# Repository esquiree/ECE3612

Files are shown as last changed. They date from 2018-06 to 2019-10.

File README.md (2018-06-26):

# ECE3612
## `Dr. Helferty's` break out board for the ATmega 324PB
_Designed by Reed Esquirell_
---

---
This PCB is designed around the ATMEL ATmega324PB XPLAINED PRO kit.  It organizes ports A-E while providing features to the programmer.  Including:
* Potentiometer for ADC
* 8 LEDs for outputs
* 8 DIP switches for input
* Seven Segment Display (SSD)
* Stepper motor circuit
* DC motor circuit
* PMOD, I2C, UART, SERVO and PING headers

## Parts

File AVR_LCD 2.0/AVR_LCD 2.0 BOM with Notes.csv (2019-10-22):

Component | Description | Part | Designer Desciption | Example Item | References | Value | Footprint | Quantity Per PCB | Datasheet
1 | Generic connector, double row, 02x10, odd/even pin numbering scheme (row 1 odd numbers, row 2 even numbers), script generated (kicad-library-utils/schlib/autogen/connector/) | Conn_02x10_Odd_Even | 2 by 10 0.1 Inch Right angle female pin header | https://www.ebay.com/itm/5PCS-2x10Pin-2-54mm-Pitch-Header-Right-Angle-Female-Double-Row-Socket-Connector/132474485107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 | BreakOut_EXT1 X-Plained_EXT1 | Conn_02x10_Odd_Even | Pin_Header_Straight_2x10_Pitch2.54mm | 2 | ~
2 | Unpolarized capacitor | C | 1uF 0805 Cap |  | C1 C2 C3 | 1uF | C_0805 | 3 | ~
3 | LED generic | LED | Green 0805 LED |  | D1 | LED | LED_0805 | 1 | ~
4 | Generic connector, single row, 01x02, script generated (kicad-library-utils/schlib/autogen/connector/) | Conn_01x02 | Battery Connector | https://www.digikey.com/product-detail/en/B2B-PH-K-S(LF)(SN)/455-1704-ND/926611/?itemSeq=284861168 | J5 | Conn_01x02 | JST_XH_B02B-XH-A_02x2.50mm_Straight | 1 | ~
5 | Generic connector, single row, 01x04, script generated (kicad-library-utils/schlib/autogen/connector/) | Conn_01x04 | 4 pos 0.1 Inch FEMALE pin header |  | J1 J2 J4 | Conn_01x04 | Pin_Header_Straight_1x04_Pitch2.54mm | 3 | ~
6 | Generic connector, double row, 02x02, odd/even pin numbering scheme (row 1 odd numbers, row 2 even numbers), script generated (kicad-library-utils/schlib/autogen/connector/) | Conn_02x02_Odd_Even | 4 pos 0.1 Inch FEMALE pin header |  | J3 | Conn_02x02_Odd_Even | Pin_Header_Straight_2x02_Pitch2.54mm | 1 | ~
7 | Resistor | R | 10k 1% |  | R2 R3 | 10K | R_0805 | 2 | ~
8 | Resistor | R | 10k 1% |  | R1 R4 | 1K | R_0805 | 2 | ~
9 | ALS31313KLEATR-1000 | ALS31313 | IC | https://www.digikey.com/product-detail/en/allegro-microsystems-llc/ALS31313KLEATR-1000/620-2007-1-ND/9805849 | U4 | ALS31313 | TSSOP-8_4.4x3mm_Pitch0.65mm | 1
10 | 0.96" I2C IIC SPI Serial 128X64 White OLED LCD LED Display Module XS | I2C_LCD | WHITE I2C LCD | https://www.ebay.com/itm/0-96-I2C-IIC-SPI-Serial-128X64-White-OLED-LCD-LED-Display-Module-XS/332947056186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 | U2 | I2C_LCD | SSD1306 | 1
11 | Generic connector, single row, 01x04, script generated (kicad-library-utils/schlib/autogen/connector/) | Conn_01x04 | 4 pos 0.1 Inch MALE pin header |  | NONE | VIEW PICTURES TO RIGHT |  | 1
12 |  | Conn_01x01 | 1 pos 0.1 Inch MALE pin header |  | NONE | VIEW PICTURES TO RIGHT |  | 4
13 | LSM6DS3TR | JOYSTICK_JS5208 | Joystick | https://www.digikey.com/products/en?keywords=eg4561-nd | U5 | JOYSTICK_JS5208 | JS5208 | 1
14 | I2C/SPI, iNEMO inertial module: always-on 3D accelerometer and 3D gyroscope | LSM6DS3 | IMU | https://www.digikey.com/product-detail/en/LSM6DS3TR/497-15383-1-ND/5180534/?itemSeq=284858849 | U1 | LSM6DS3 | Bosch_LGA-14_3x2.5mm_Pitch0.5mm | 1 | www.st.com/resource/en/datasheet/lsm6ds3.pdf
15 | TMP75AIDGKR | TMP75 | Temp Sensor | https://www.digikey.com/product-detail/en/texas-instruments/TMP75AIDGKR/296-26837-1-ND/2255196 | U3 | TMP75 | 8-TSSOP (1.27mm PITCH, 5.4mm WIDTH) | 1
 |  |  |  |  |  |  |  |  |  | *** TRIM EXCESS HEIGHT FROM HEADERS
Component Groups: | 15
Component Count: | 25
Fitted Components: | 25
Number of PCBs: | 1
Total components: | 25
Schematic Version:
Schematic Date:
BoM Date: | 2/20/2019 17:40
Schematic Source: | C:\Users\Reed\Documents\Doc H LCD\AVR_LCD 2.0\AVR_LCD 2.0.sch
KiCad Version: | Eeschema (5.0.0)

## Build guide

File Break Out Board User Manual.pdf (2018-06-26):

# Break Out Board User Manual

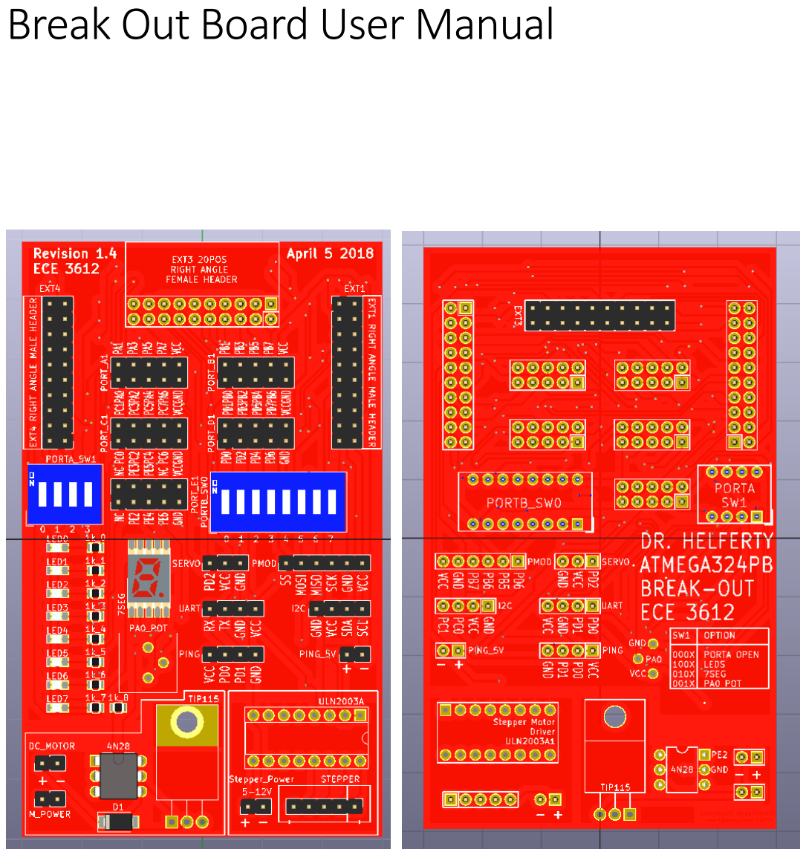
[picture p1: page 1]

## Contents

PORT A | 3
1. Analog Input (ADC0-7) | 3
2. LED Output | 3
3. Seven Segment Display | 4
PORT B | 4
1. DIP Switch | 4
2. PMOD | 4
PORT C | 5
1. I2C Interface | 5
PORT D | 5
1. UART Interface | 5
2. Servo Motor | 5
3. PMOD | 5
4. PING Sensor | 6
PORT E | 6
1. DC Motor | 6
2. Stepper Motor | 6
PCB Layers | 7

## PORT A

PORT A has three purposes:

1. Analog Input (ADC0-7). PA0(ADC0) is connected to the potentiometer through PORTA_SW1. To enable the potentiometer, PORTA_SW1 needs to be set properly. The first two switches need to be turned ON (labeled 0&1 on the silkscreen), this leaves PORTA floating. If these are enabled, the analog input will be pulled to ground. Next to use the potentiometer, enable switch 2.

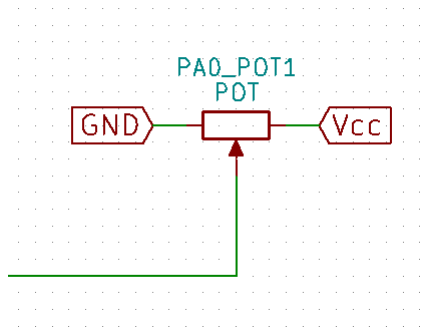
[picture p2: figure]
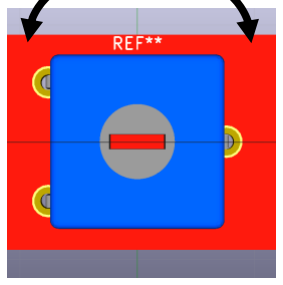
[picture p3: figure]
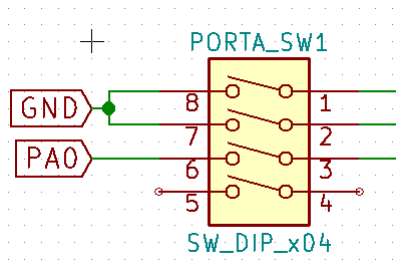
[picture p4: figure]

2. LED Output. LED0-LED7 are connected to PA0-PA7 through 1k Ohm resistors. To complete the circuit, giving the LEDs a path to ground, PORTA_SW1 0 must be enabled. If LED0 does not turn ON/OFF properly, turn off PORTA_SW1 2.
GND | VCC

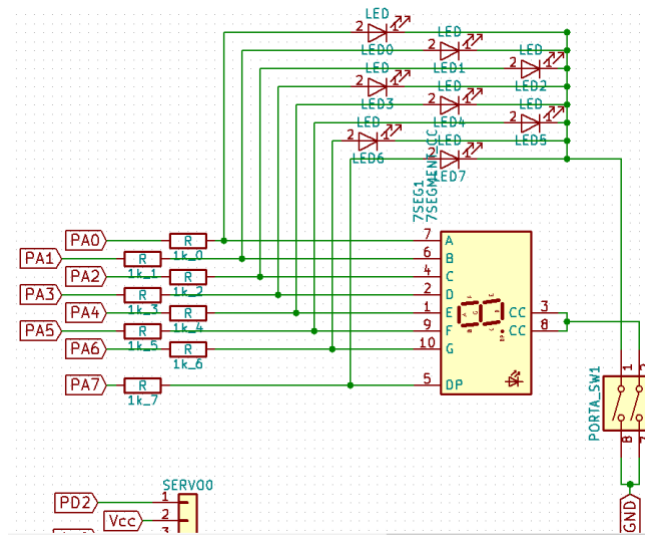
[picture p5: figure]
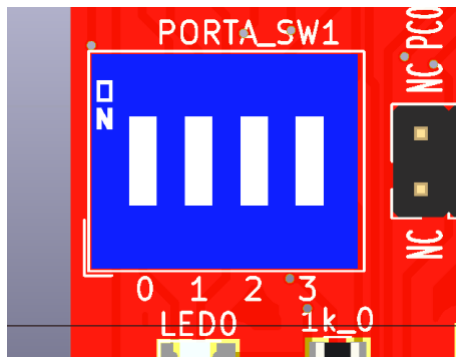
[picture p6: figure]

3. Seven Segment Display. The LEDs inside this KCS02 package use the same current limiting 1k Ohm resistors as the 8 individual LEDs. This is a common cathode (CC) device. To enable the SSD, set PORTA_SW1 1 to ON. Disable PORTA_SW1 2 if segment A is not working properly.

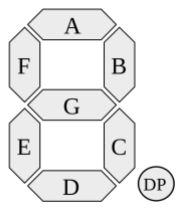
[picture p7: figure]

## PORT B

PORT B has two purposes:

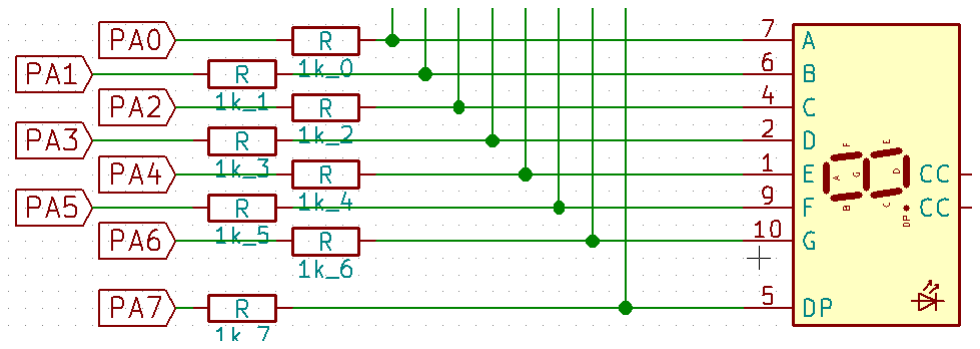
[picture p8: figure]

1. DIP Switch. This switch connects PB0-PB7 to ground when enabled. Remember to use the internal pull up resistors when using this input.

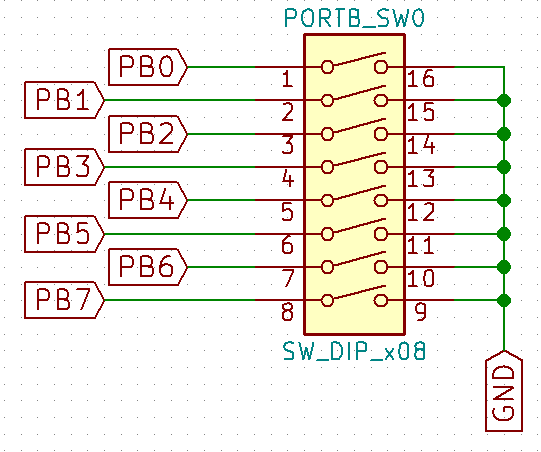
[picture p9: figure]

2. PMOD. The ATmega324PB uses PB5-PB7 for the SPI communications. When using this header, disable the corresponding switches on PORT B to leave them floating.

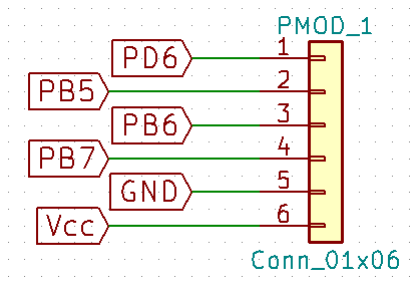
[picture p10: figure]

## PORT C

1. I2C Interface. PC0 and PC1 are used for hardware I2C communications in the ATmega 324PB. VCC is 3.3V.

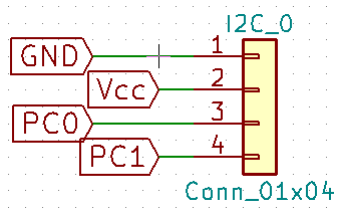
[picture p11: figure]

2. PC2-5 are used for JTAG communications and can not be accessed by default.

## PORT D

Port D has four purposes:

1. UART Interface. PD0 and PD1 are used for hardware UART communications in the ATmega 324PB. VCC is 3.3V.

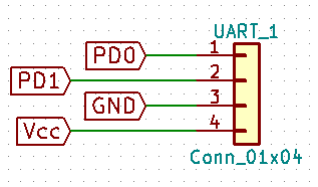
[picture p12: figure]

2. Servo Motor. PD2 is used to control the servo through PWM. VCC is 3.3V.

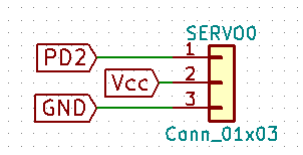
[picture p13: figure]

3. PMOD. PD6 is used as the slave select line for the hardware PMOD communications in the ATmega 324PB.

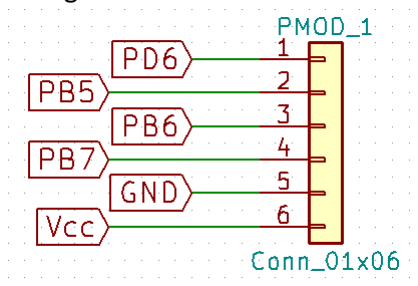
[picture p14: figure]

4. PING Sensor. The ping sensor requires 5V power. A female to female jumper wire can be used to get 5V from the USB input to the XPLAINED board.

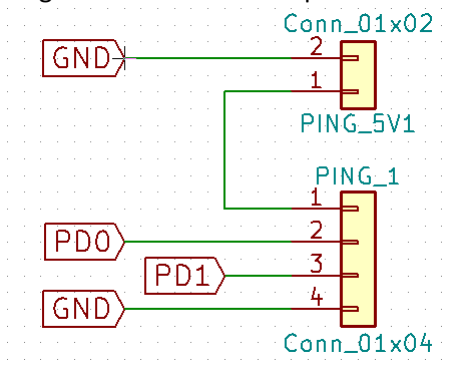
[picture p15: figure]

## PORT E

Port E has two purposes:

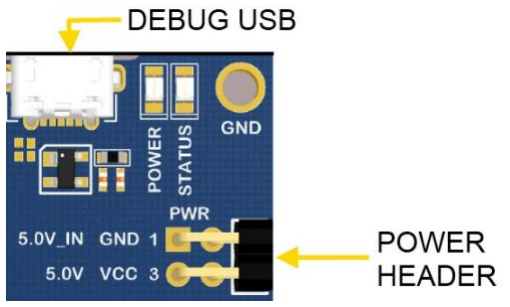
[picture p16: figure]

1. DC Motor. PE2 is connected to a 4N28 opto-isolator. This IC prevents noise and feedback from being introduced. A PNP Darlington transistor is used to amplify the signal. An external power source is needed.

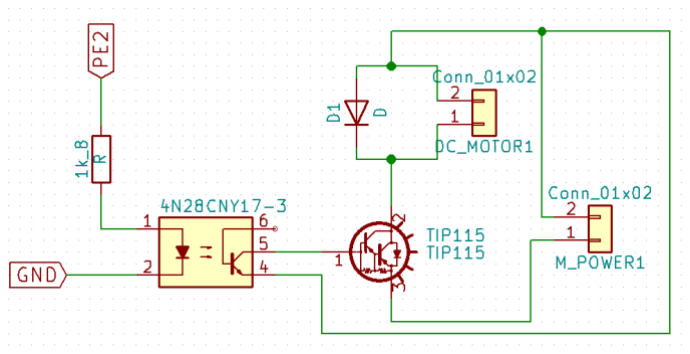
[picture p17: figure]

2. Stepper Motor. PE3-6 are connected to the ULN2003A IC. This IC amplifies the signals. An External power source is needed. 5V is the minimum and 12V is the maximum.

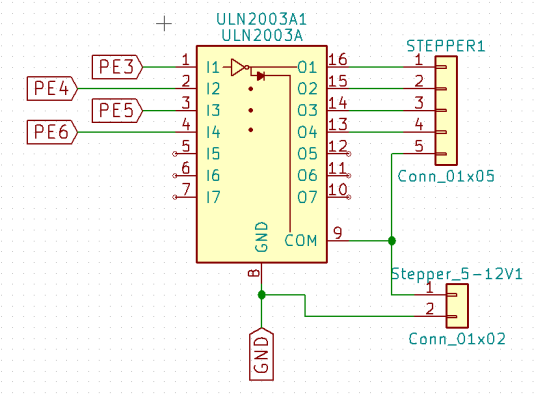
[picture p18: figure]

## PCB Layers

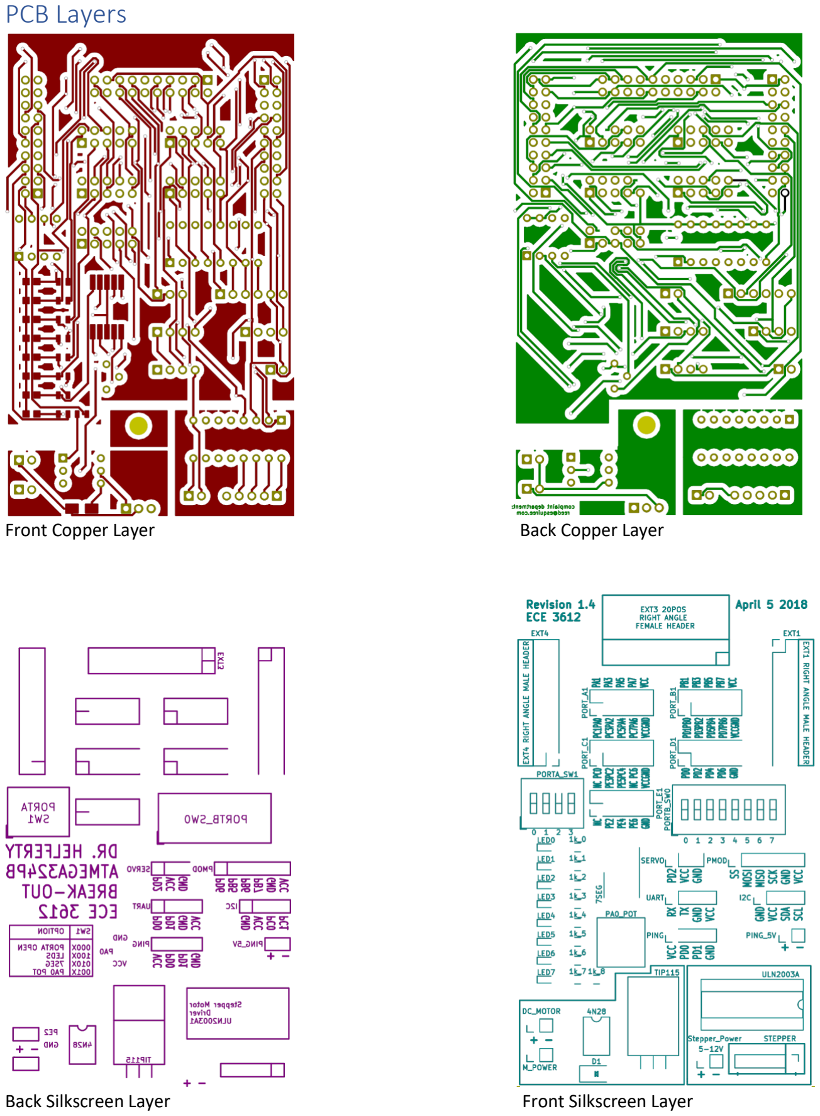
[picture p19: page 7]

Front Copper Layer | Back Copper Layer
Back Silkscreen Layer | Front Silkscreen Layer

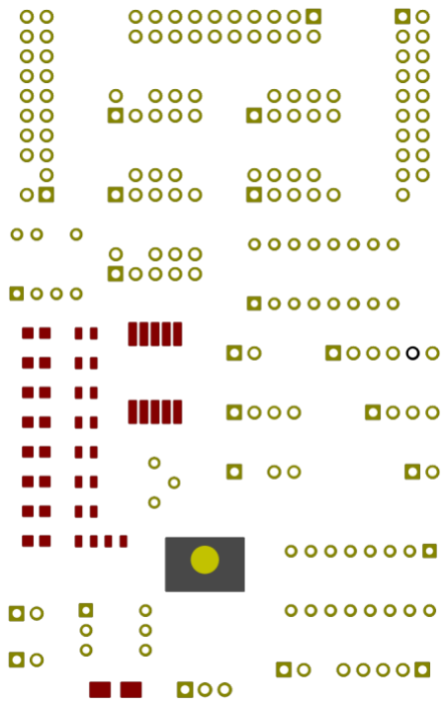
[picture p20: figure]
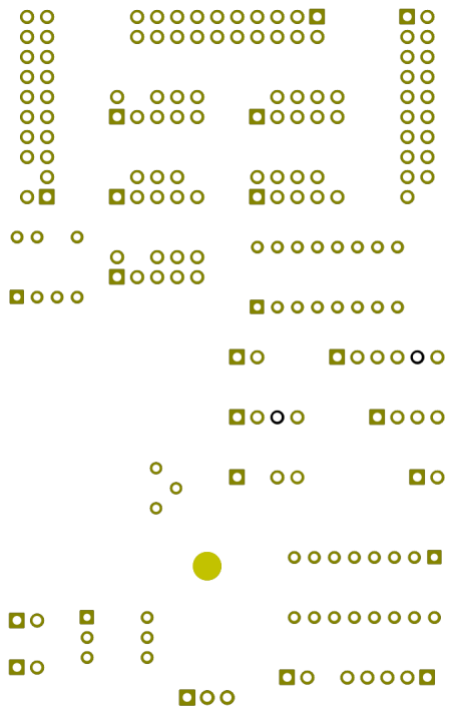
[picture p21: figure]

Front Solder Mask Layer | Bottom Solder Mask Layer

Designed using KiCad, a free and open source EDA.

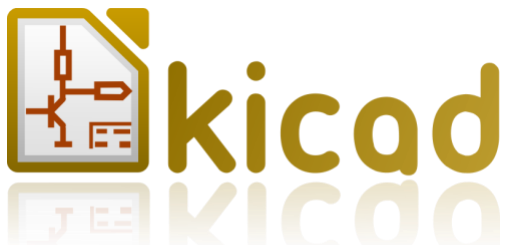
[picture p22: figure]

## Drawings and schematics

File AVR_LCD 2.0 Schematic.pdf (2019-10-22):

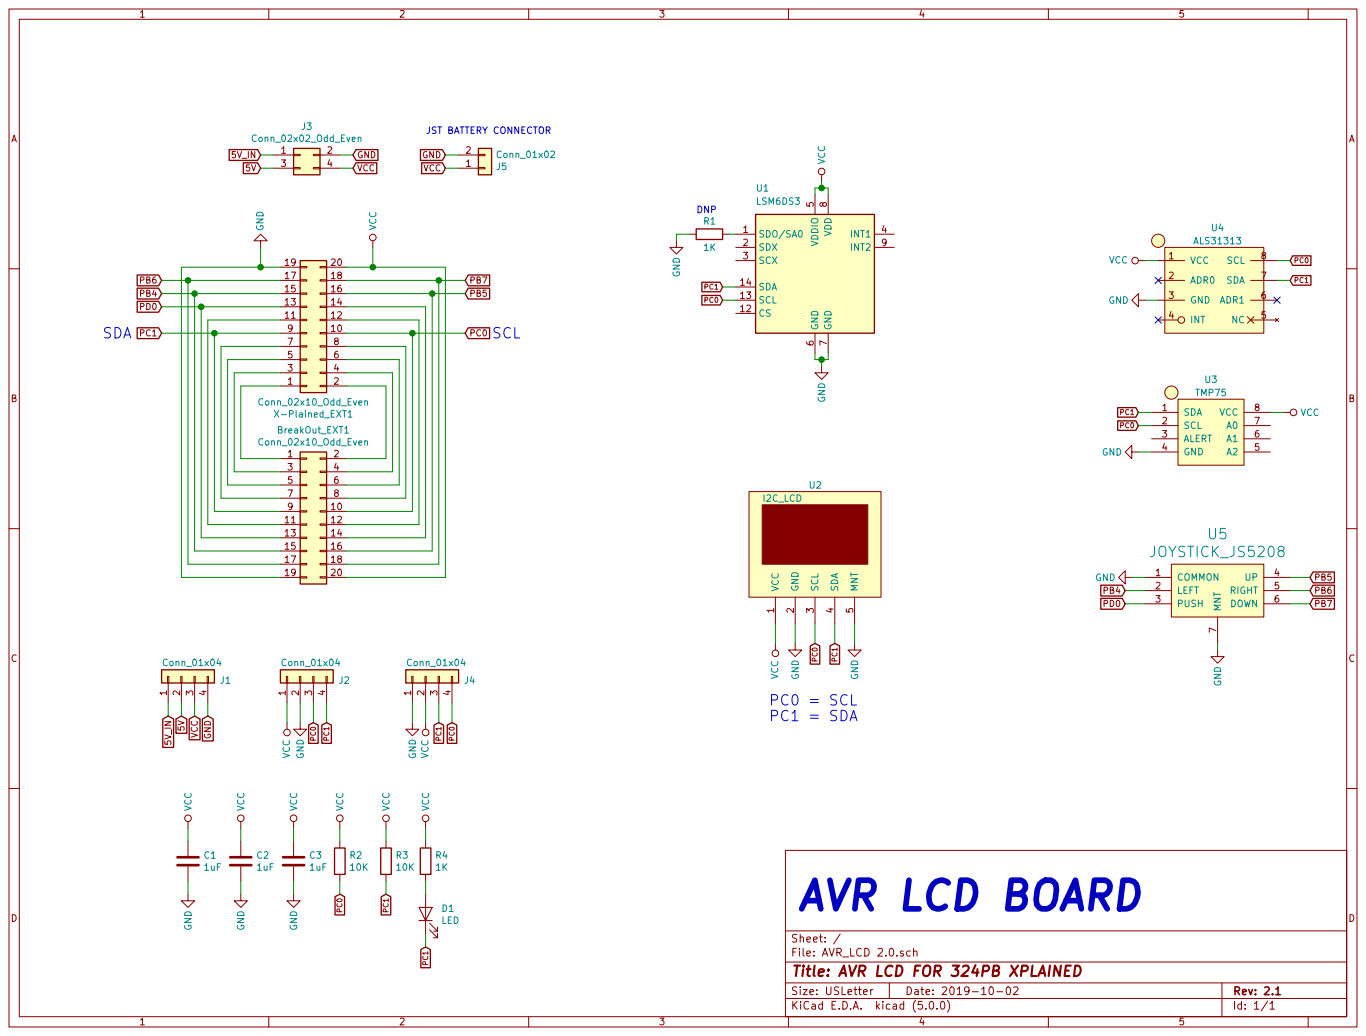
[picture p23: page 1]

Id: 1/1 Title: AVR LCD FOR 324PB XPLAINED

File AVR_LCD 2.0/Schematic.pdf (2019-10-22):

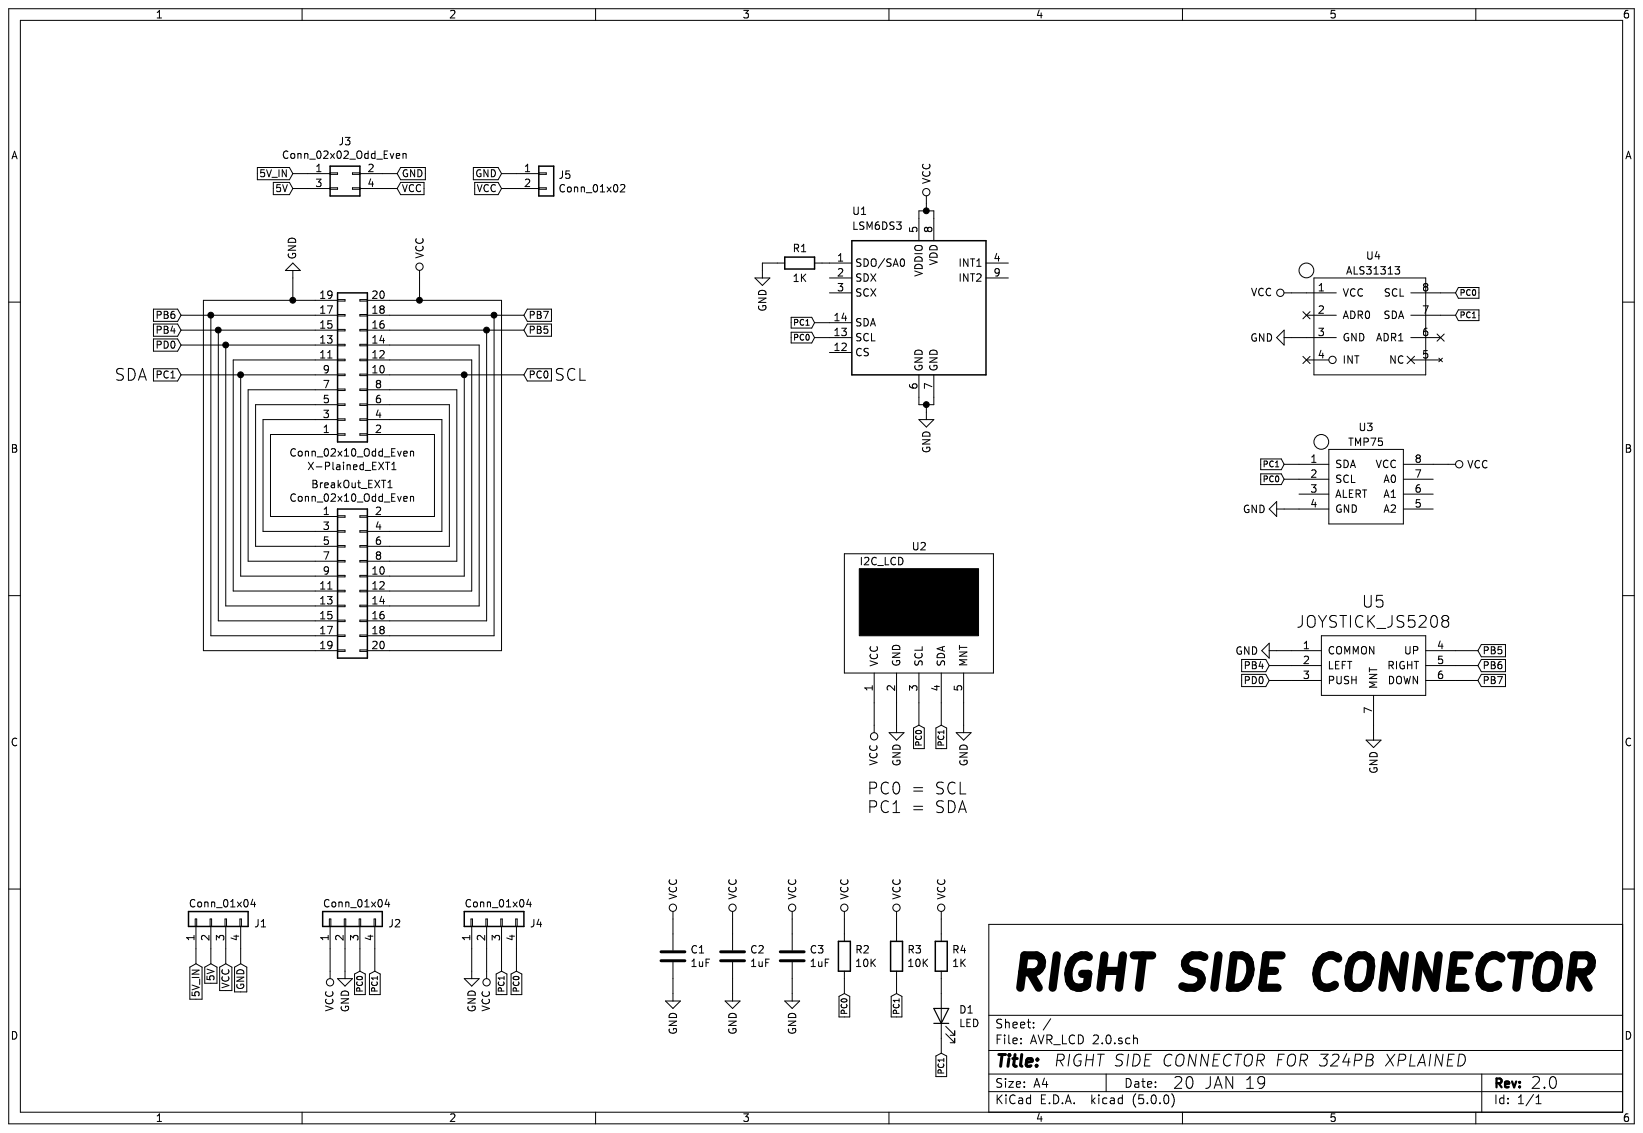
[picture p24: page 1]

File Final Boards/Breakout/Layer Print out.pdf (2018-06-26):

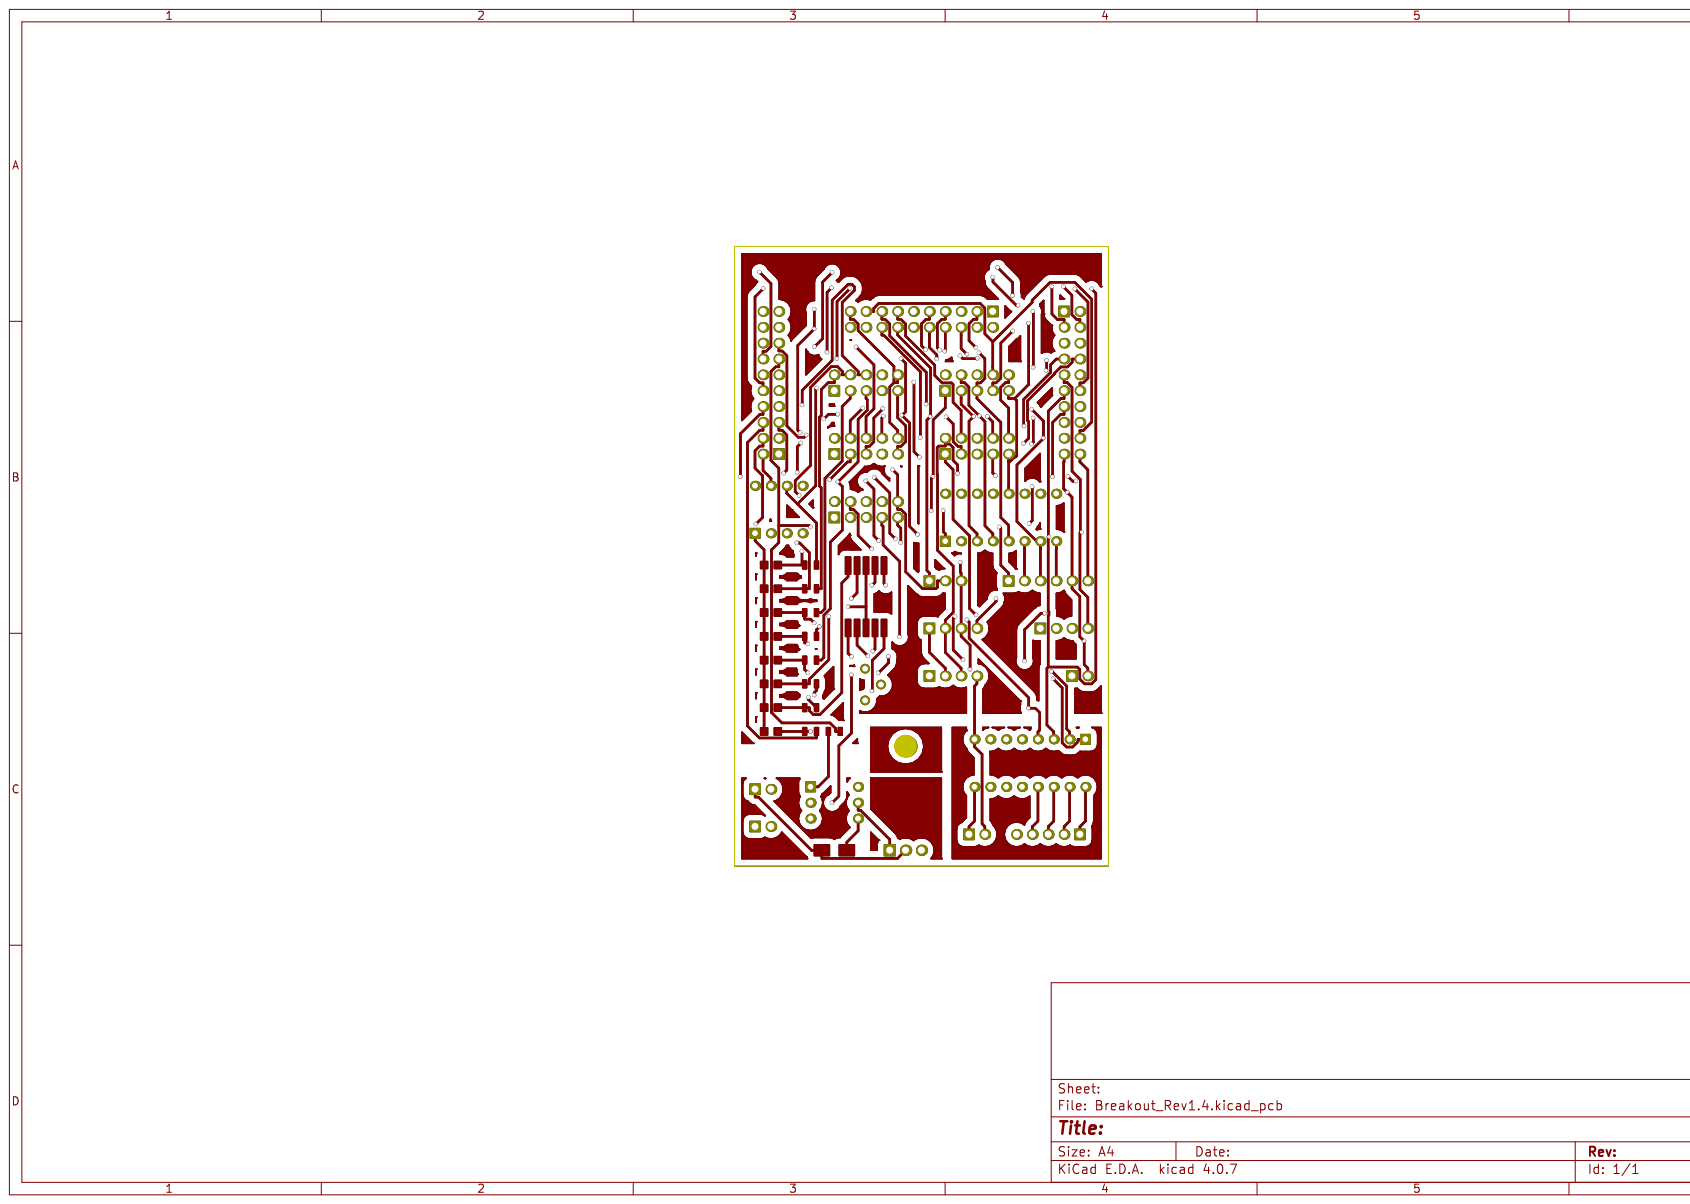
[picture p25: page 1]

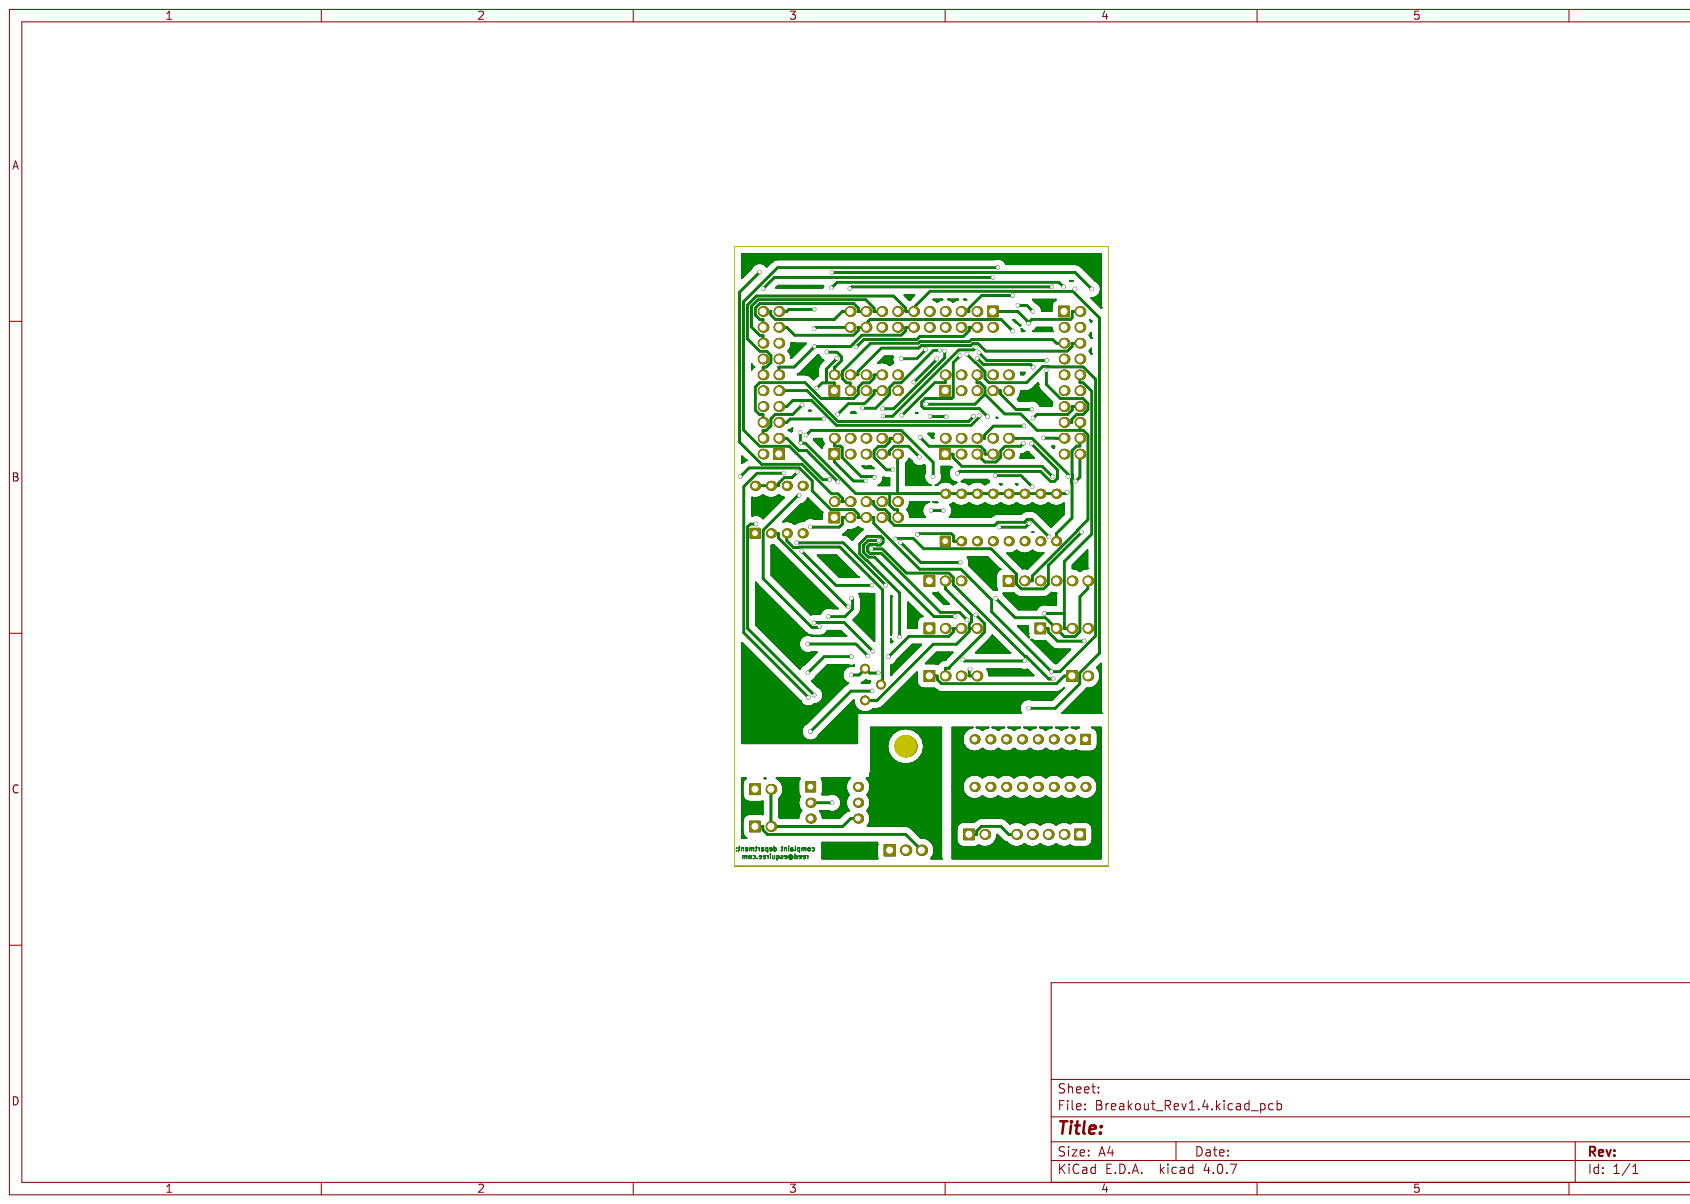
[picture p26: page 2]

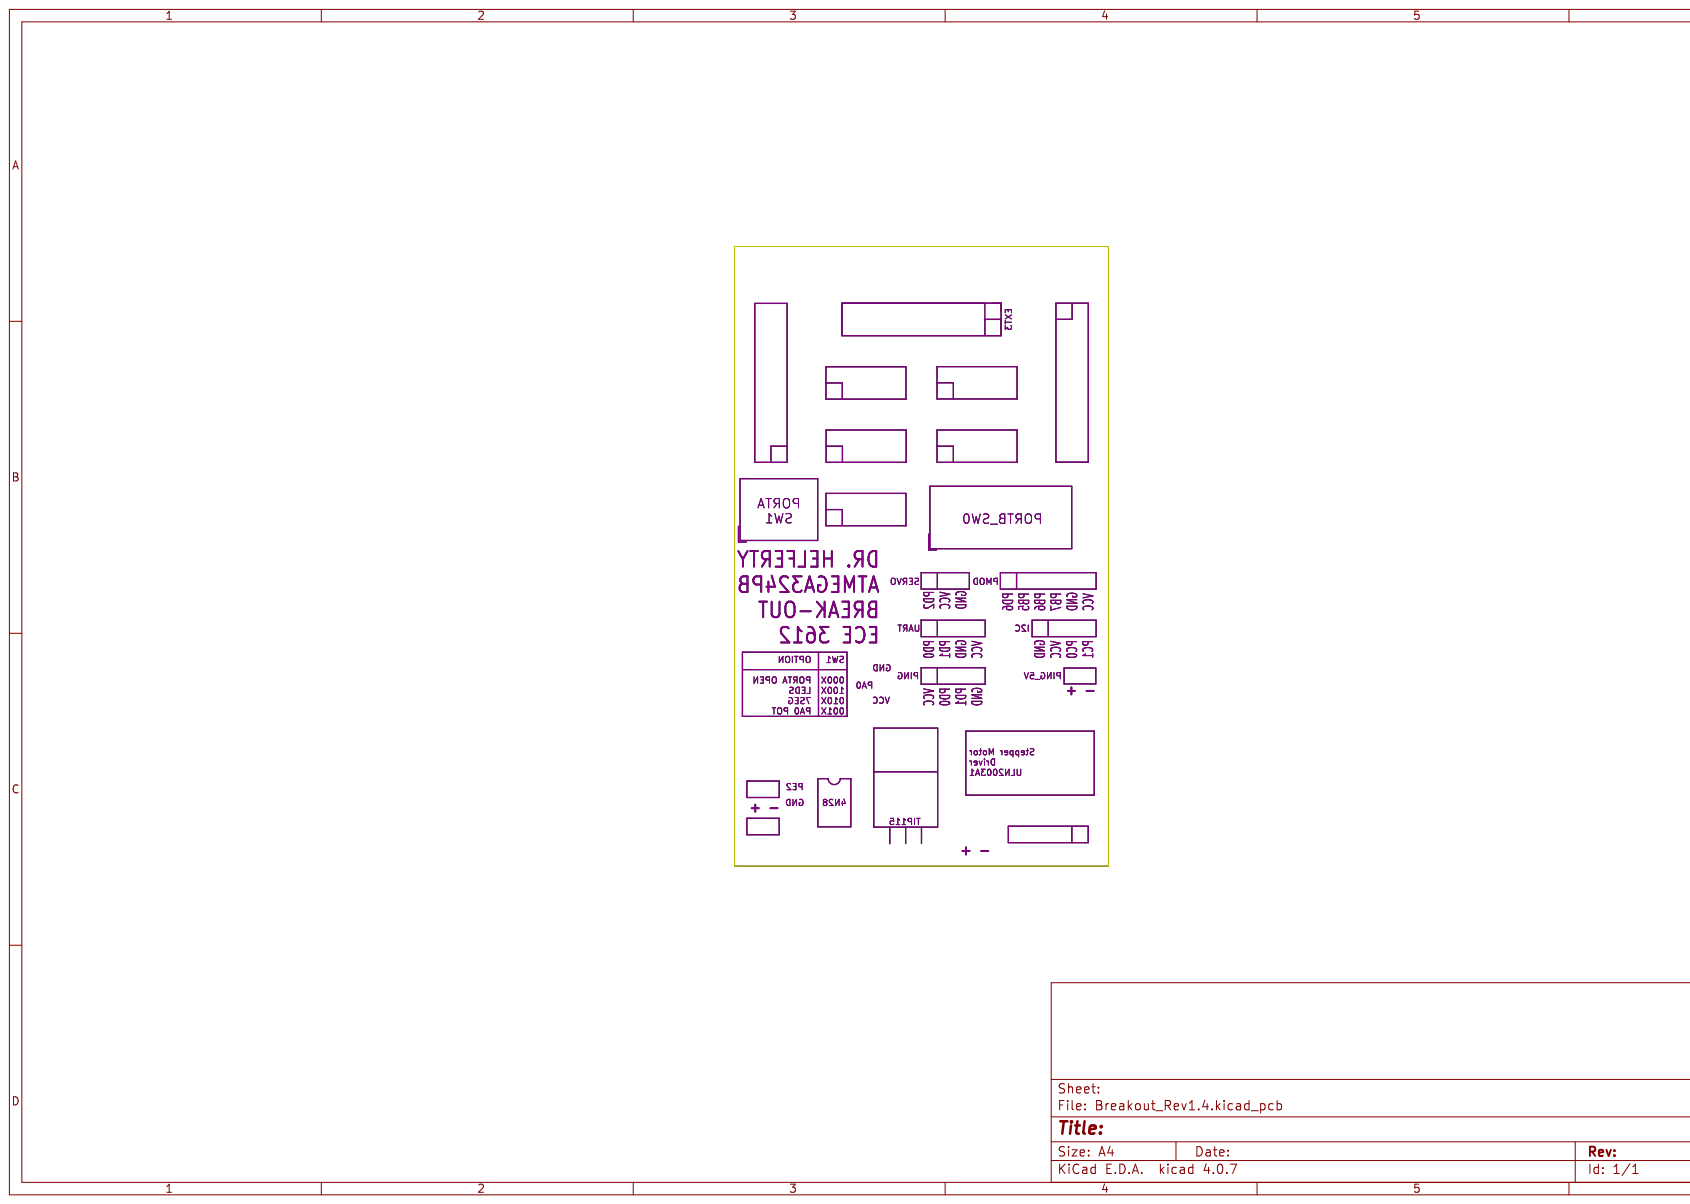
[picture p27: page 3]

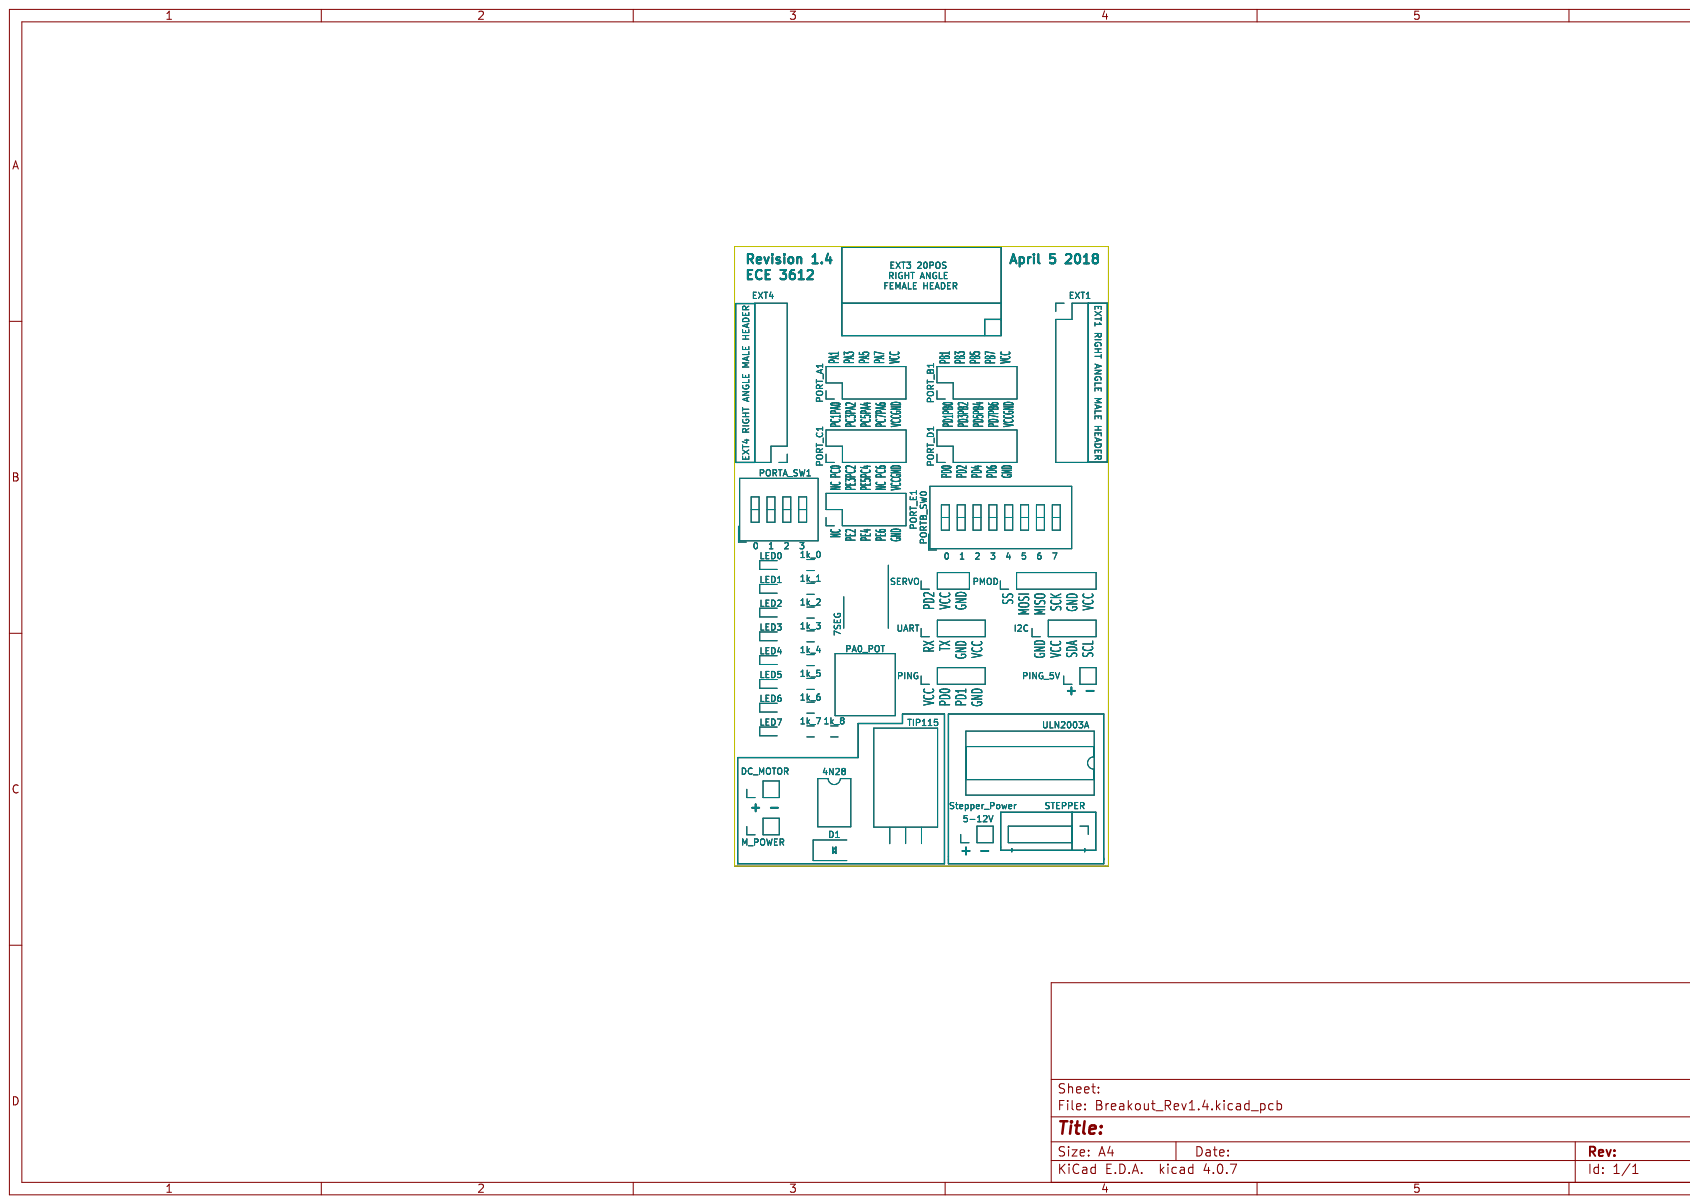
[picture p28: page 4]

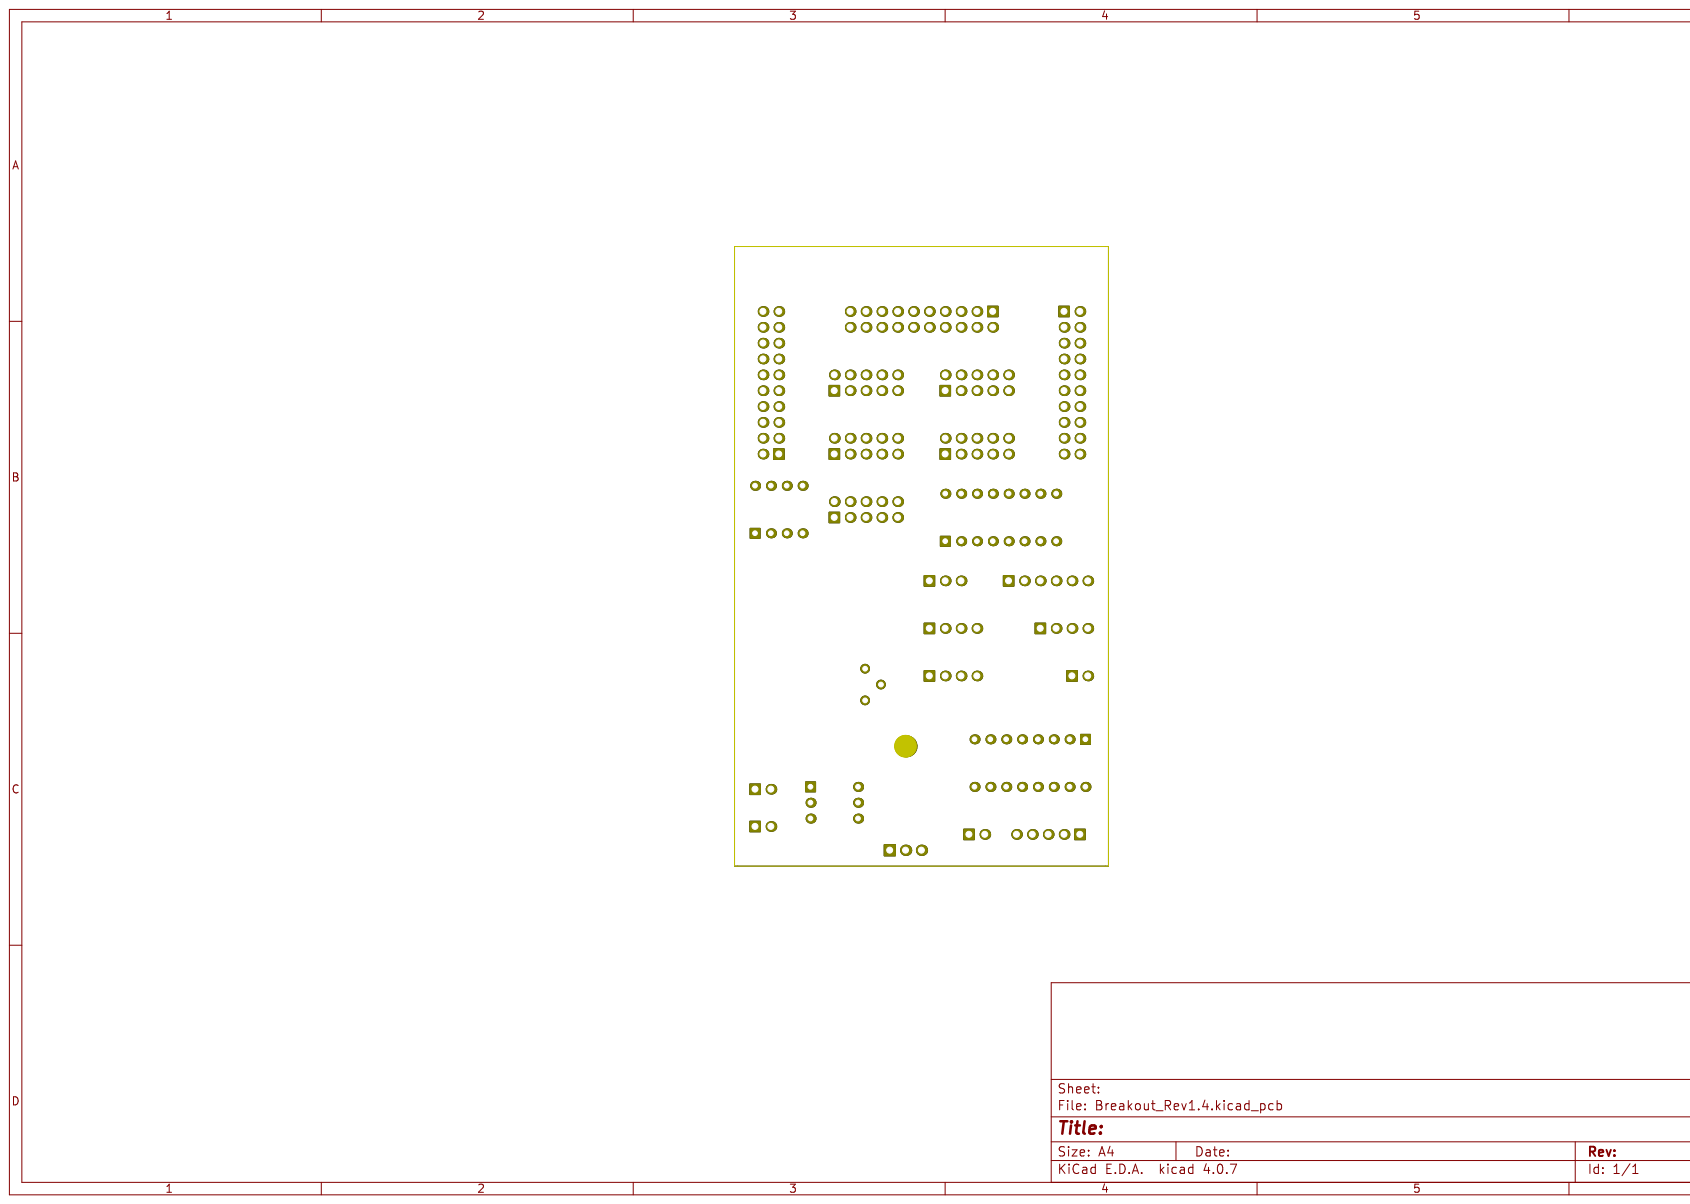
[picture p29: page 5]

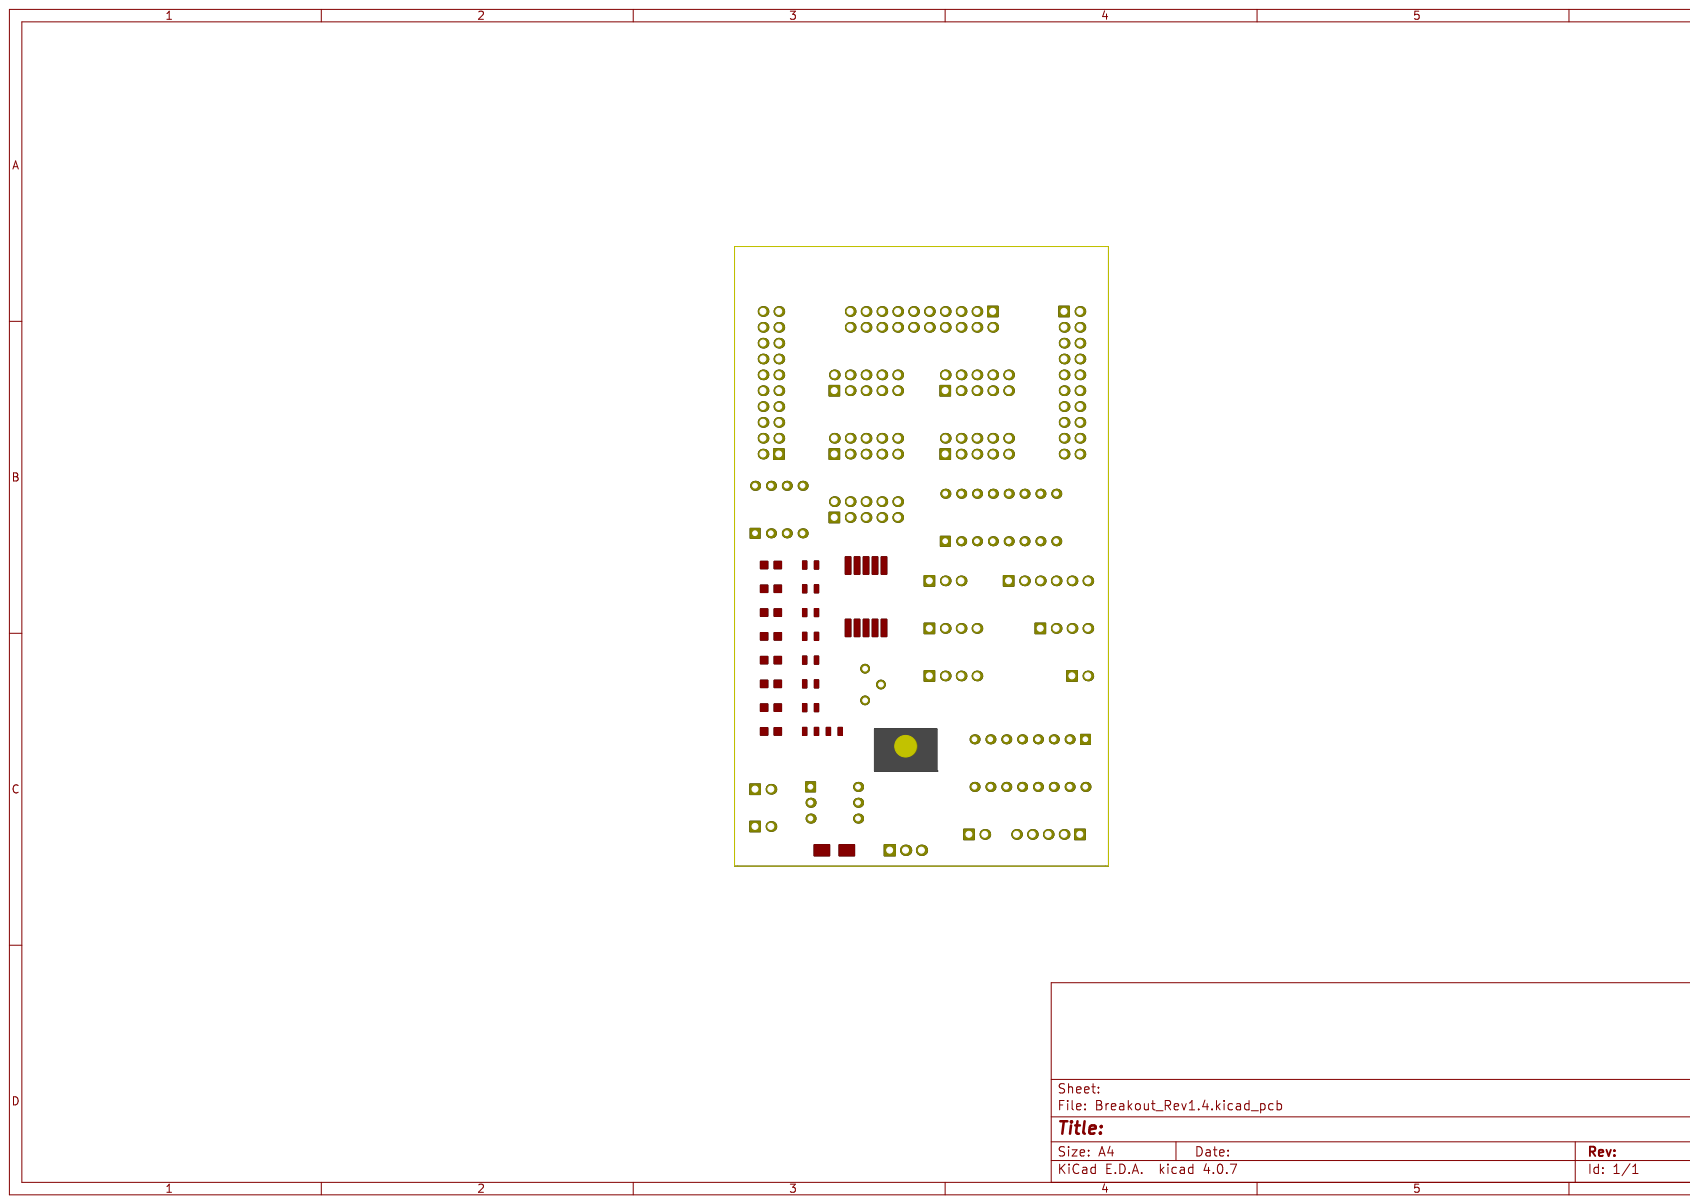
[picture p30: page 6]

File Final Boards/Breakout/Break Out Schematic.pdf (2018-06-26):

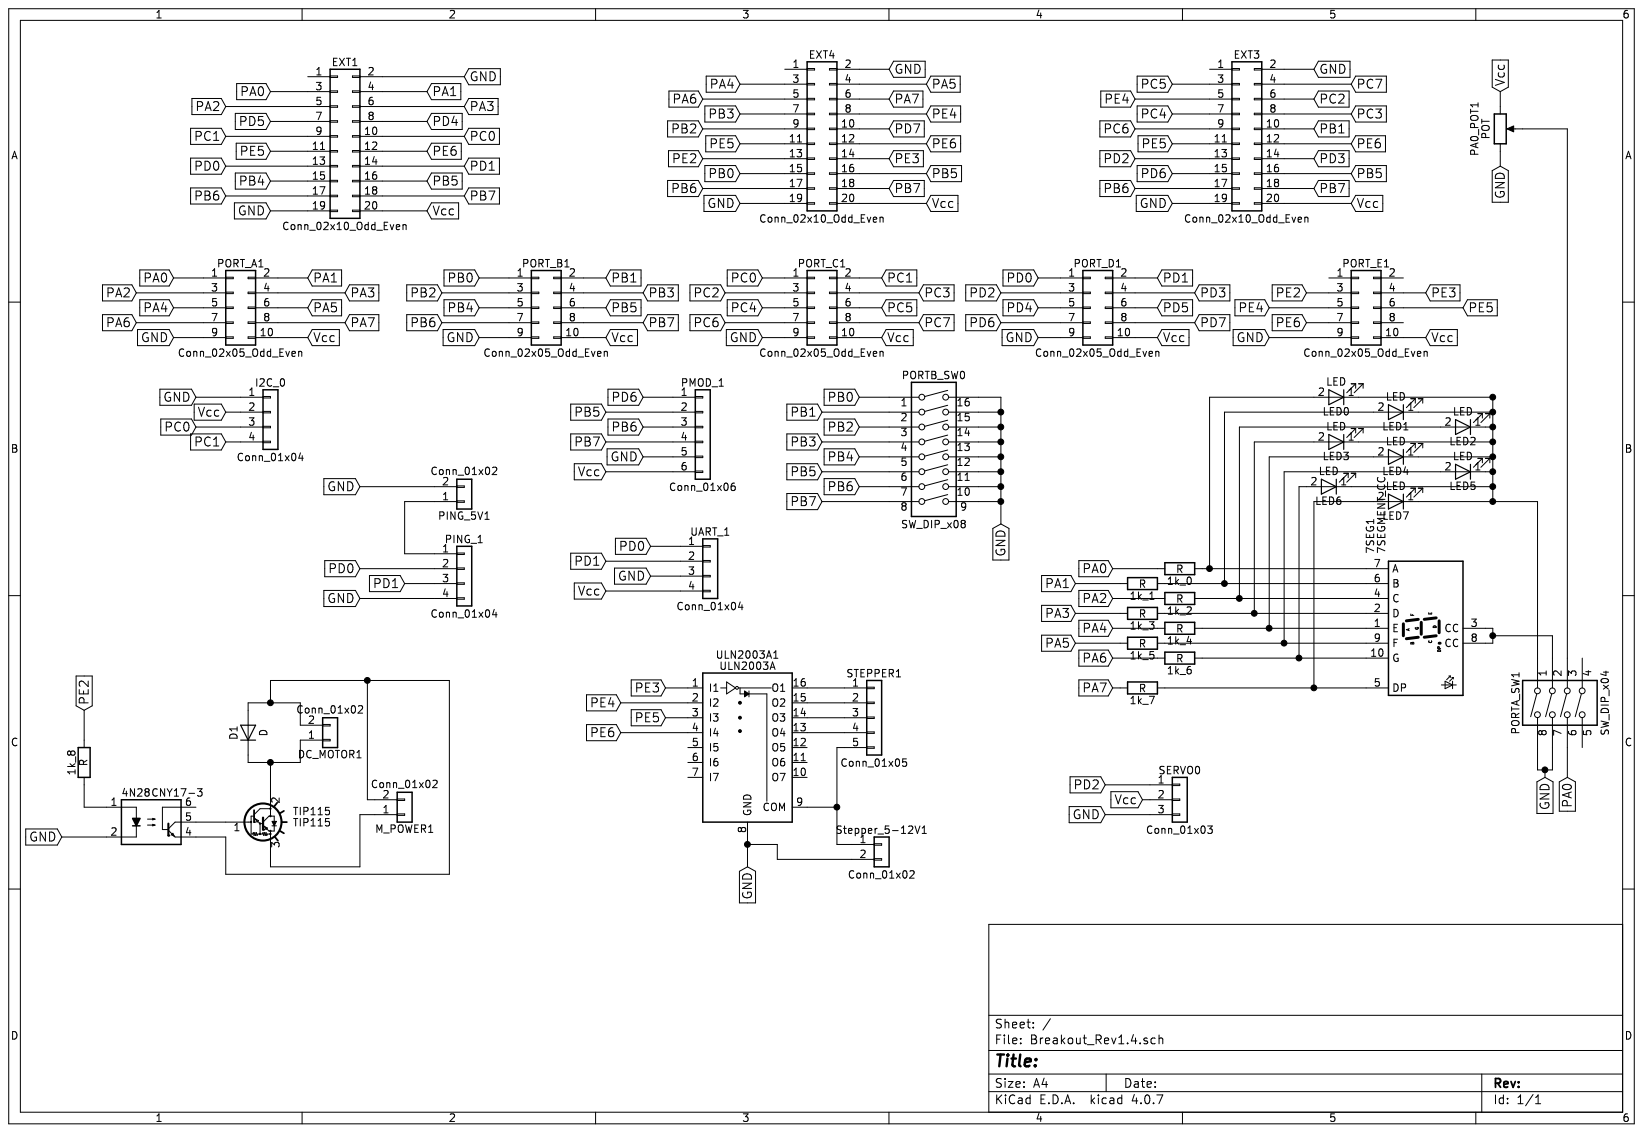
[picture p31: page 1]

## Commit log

2018-06-26 Board Files
    [Breakout_Rev1.4-B.Adhes.gbr, Breakout_Rev1.4-B.CrtYd.gbr, Breakout_Rev1.4-B.Cu.gbr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]
2019-10-22 AVR LCD
    [AVR_LCD 2.0 BOM with Notes.csv, AVR_LCD 2.0 BOM with Notes.xlsx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]
